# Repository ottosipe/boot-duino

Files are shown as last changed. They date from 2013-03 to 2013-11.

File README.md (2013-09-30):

boot-duino
==========

Arduino-based research project at the University of Michigan. Focusing on an open-source solution to gait and posture analysis.

## Project Status as of Sept. 30, 2013
- Hardware 3.0 is stable
- Software can collect, save, or transmit IMU data.
- Case is designed and being tested.

## Programming

- Program Upload via BT: `make upload`
- Program Upload via AVRisp mkII: `make program`
- Bootloader: `make bootload`
- Fuses: `make fuses`

----

Bluetooth Settings:  
`ST,255` 	- command timer  
`SU,38` 	- baud rate 38400  
`S~,3` 		- Set Modem Profile   

Fuse Info: [Arduino Fuses](http://www.codingwithcody.com/2011/04/arduino-default-fuse-settings/), [Fuse Calculator](http://www.engbedded.com/fusecalc/)

----

Hardware Notes

- Chip Select Pin : D5

----

Install Arduino-Makefile:  

```
sudo perl -MCPAN -e shell
	install YAML
	install Device::SerialPort
```

## Resources and Libraries:
 
- [I2CDev](https://github.com/jrowberg/i2cdevlib)
- [SDFat](http://code.google.com/p/sdfatlib/downloads/list)
- [Arduino-Makefile](https://github.com/mjoldfield/Arduino-Makefile)

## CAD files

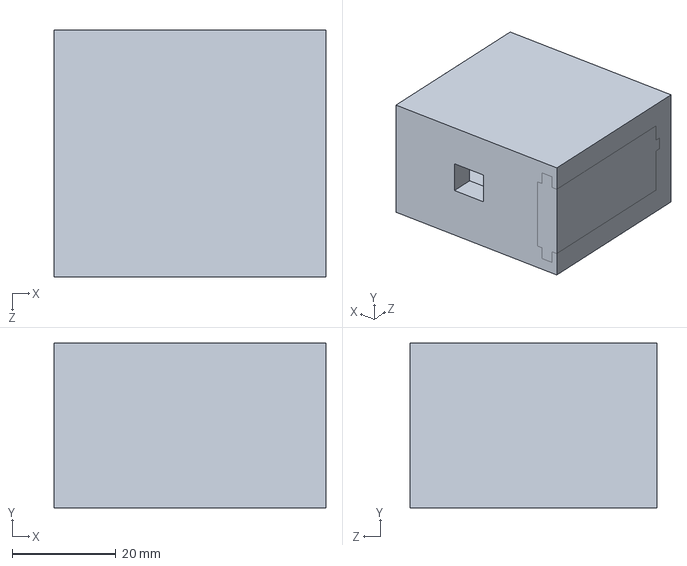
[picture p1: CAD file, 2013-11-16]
Case.SLDPRT
52.4 x 31.8 x 47.6 mm

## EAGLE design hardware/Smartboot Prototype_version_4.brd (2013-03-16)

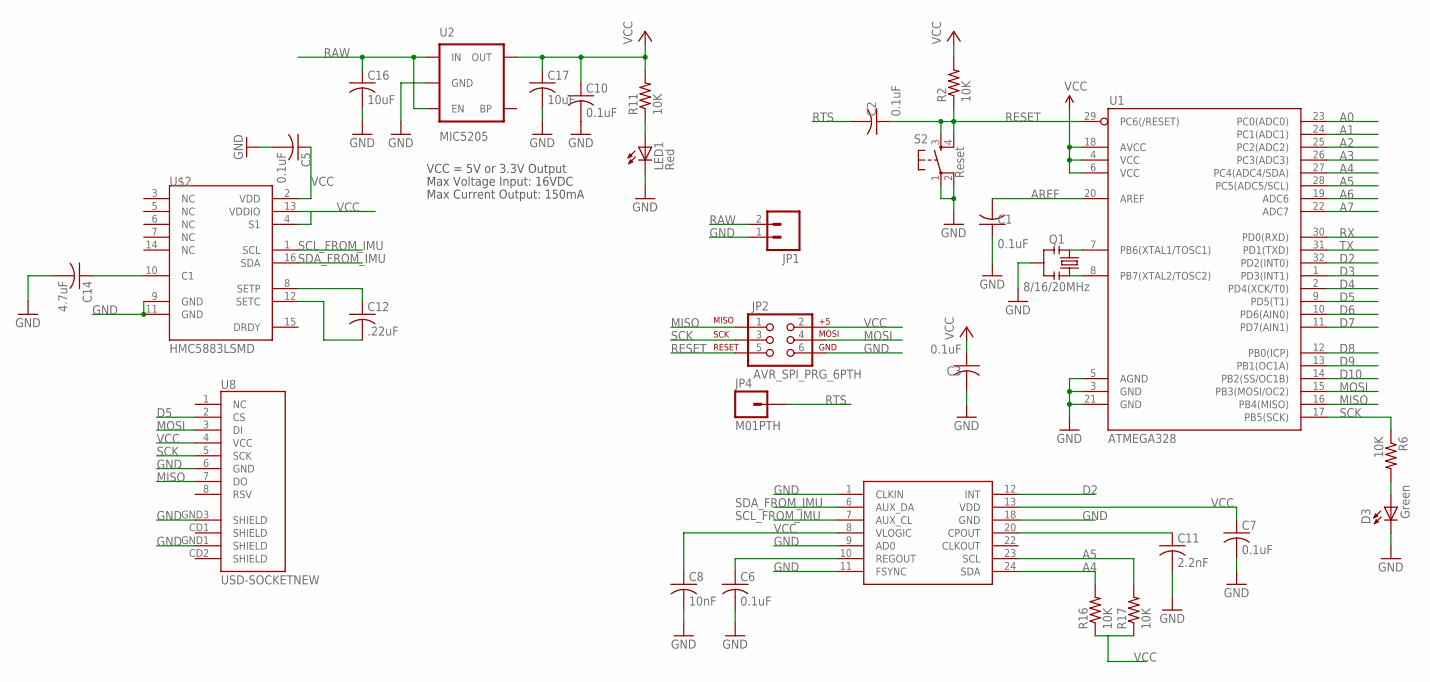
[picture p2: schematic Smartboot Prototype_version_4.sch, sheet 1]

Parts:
C1, C2, C3, C5, C6, C7, C10: 0.1uF; C0603
C8: 10nF; C0603
C11: 2.2nF; C0603
C12: .22uF; C0603
C14: 4.7uF; C0603
C16, C17: 10uF; C0603
D3: Green; LED-0603
JP1: M02-JST-2MM-SMT; JST-2-SMD
JP2: AVR_SPI_PRG_6PTH; 2X3
JP4: M01PTH; 1X01
LED1: Red; LED-0603
Q1: 8/16/20MHz; RESONATOR-SMD
R2, R6, R11, R16, R17: 10K; R0603
S2: Reset; TACTILE_SWITCH_SMD
U1: ATMEGA328; TQFP32-08
U2: MIC5205; SOT23-5
U8: USD-SOCKETNEW; MICRO-SD-SOCKET-PP
U$2: HMC5883LSMD; 16LPCC
U$5: MPU-6050A; QFN-24-NP

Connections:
A0: U1.23 (PC0(ADC0))
A1: U1.24 (PC1(ADC1))
A2: U1.25 (PC2(ADC2))
A3: U1.26 (PC3(ADC3))
A4: R16.2, U1.27 (PC4(ADC4/SDA)), U$5.24 (SDA)
A5: R17.2, U1.28 (PC5(ADC5/SCL)), U$5.23 (SCL)
A6: U1.19 (ADC6)
A7: U1.22 (ADC7)
AREF: C1.2, U1.20 (AREF)
D2: U1.32 (PD2(INT0)), U$5.12 (INT)
D3: U1.1 (PD3(INT1))
D4: U1.2 (PD4(XCK/T0))
D5: U1.9 (PD5(T1)), U8.2 (CS)
D6: U1.10 (PD6(AIN0))
D7: U1.11 (PD7(AIN1))
D8: U1.12 (PB0(ICP))
D9: U1.13 (PB1(OC1A))
D10: U1.14 (PB2(SS/OC1B))
GND: C1.1, C3.2, C5.2, C6.2, C7.2, C8.2, C10.2, C11.2, C14.2, C16.2, C17.2, D3.C, JP1.1 (2), JP2.6, LED1.C, Q1.2, S2.1, S2.2, U1.3 (GND), U1.5 (AGND), U1.21 (GND), U2.2 (GND), U8.6 (GND), U8.GND1 (SHIELD), U8.GND3 (SHIELD), U$2.9 (GND), U$2.11 (GND), U$5.1 (CLKIN), U$5.9 (AD0), U$5.11 (FSYNC), U$5.18 (GND); also elsewhere on the board
MISO: JP2.1, U1.16 (PB4(MISO)), U8.7 (DO)
MOSI: JP2.4, U1.15 (PB3(MOSI/OC2)), U8.3 (DI)
unnamed: Q1.1, U1.8 (PB7(XTAL2/TOSC2))
unnamed: Q1.3, U1.7 (PB6(XTAL1/TOSC1))
unnamed: D3.A, R6.2
unnamed: C12.1, U$2.8 (SETP)
unnamed: C12.2, U$2.12 (SETC)
unnamed: C14.1, U$2.10 (C1)
unnamed: C6.1, U$5.10 (REGOUT)
unnamed: C11.1, U$5.20 (CPOUT)
unnamed: LED1.A, R11.1
RAW: C16.1, JP1.2 (1), U2.1 (IN), U2.3 (EN); also elsewhere on the board
RESET: C2.1, JP2.5, R2.1, S2.3, S2.4, U1.29 (PC6(/RESET))
RTS: C2.2, JP4.1; also elsewhere on the board
RX: U1.30 (PD0(RXD)); also elsewhere on the board
SCK: JP2.3, R6.1, U1.17 (PB5(SCK)), U8.5 (SCK)
SCL_FROM_IMU: U$2.1 (SCL), U$5.7 (AUX_CL)
SDA_FROM_IMU: U$2.16 (SDA), U$5.6 (AUX_DA)
TX: U1.31 (PD1(TXD)); also elsewhere on the board
VCC: C3.1, C5.1, C7.1, C8.1, C10.1, C17.1, JP2.2, R2.2, R11.2, R16.1, R17.1, U1.4 (VCC), U1.6 (VCC), U1.18 (AVCC), U2.5 (OUT), U8.4 (VCC), U$2.2 (VDD), U$2.4 (S1), U$2.13 (VDDIO), U$5.8 (VLOGIC), U$5.13 (VDD); also elsewhere on the board

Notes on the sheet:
Max Voltage Input: 16VDC
Max Current Output: 150mA
VCC = 5V or 3.3V Output

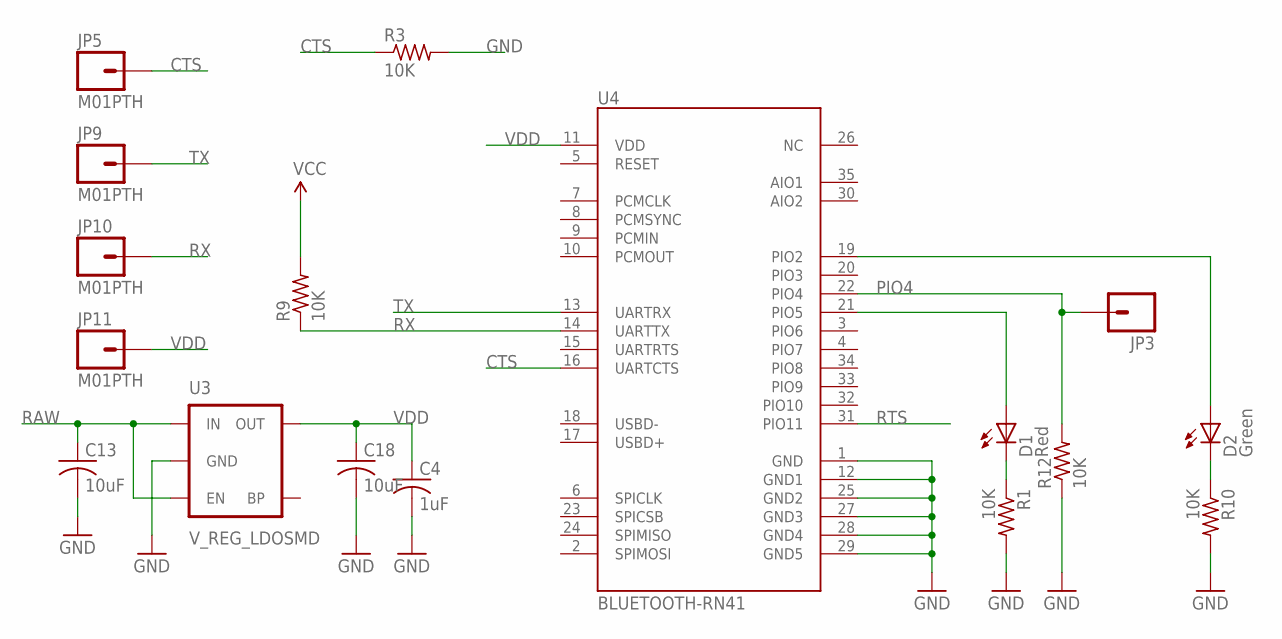
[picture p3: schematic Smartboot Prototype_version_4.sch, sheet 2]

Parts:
C4: 1uF; C0603
C13, C18: 10uF; C0603
D1: Red; LED-0603
D2: Green; LED-0603
JP3: M01SMDNS; 1X01NS
JP5, JP9, JP10, JP11: M01PTH; 1X01
R1, R3, R9, R10, R12: 10K; R0603
U3: V_REG_LDOSMD; SOT23-5
U4: BLUETOOTH-RN41; RN41

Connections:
CTS: JP5.1, R3.1, U4.16 (UARTCTS)
D1: D1.C, R1.1
D11: D2.C, R10.1
GND: C4.2, C13.2, C18.2, R1.2, R3.2, R10.2, R12.1, U3.2 (GND), U4.1 (GND), U4.12 (GND1), U4.25 (GND2), U4.27 (GND3), U4.28 (GND4), U4.29 (GND5); also elsewhere on the board
unnamed: D1.A, U4.21 (PIO5)
unnamed: D2.A, U4.19 (PIO2)
PIO4: JP3.1, R12.2, U4.22 (PIO4)
RAW: C13.1, U3.1 (IN), U3.3 (EN); also elsewhere on the board
RTS: U4.31 (PIO11); also elsewhere on the board
RX: JP10.1, R9.1, U4.14 (UARTTX); also elsewhere on the board
TX: JP9.1, U4.13 (UARTRX); also elsewhere on the board
VCC: R9.2; also elsewhere on the board
VDD: C4.1, C18.1, JP11.1, U3.5 (OUT), U4.11 (VDD)

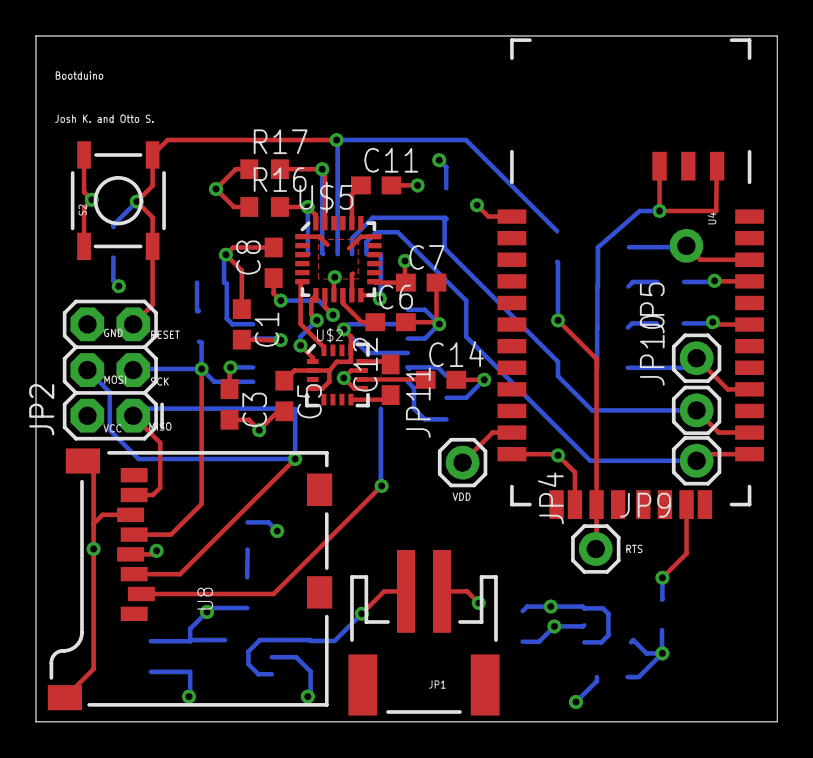
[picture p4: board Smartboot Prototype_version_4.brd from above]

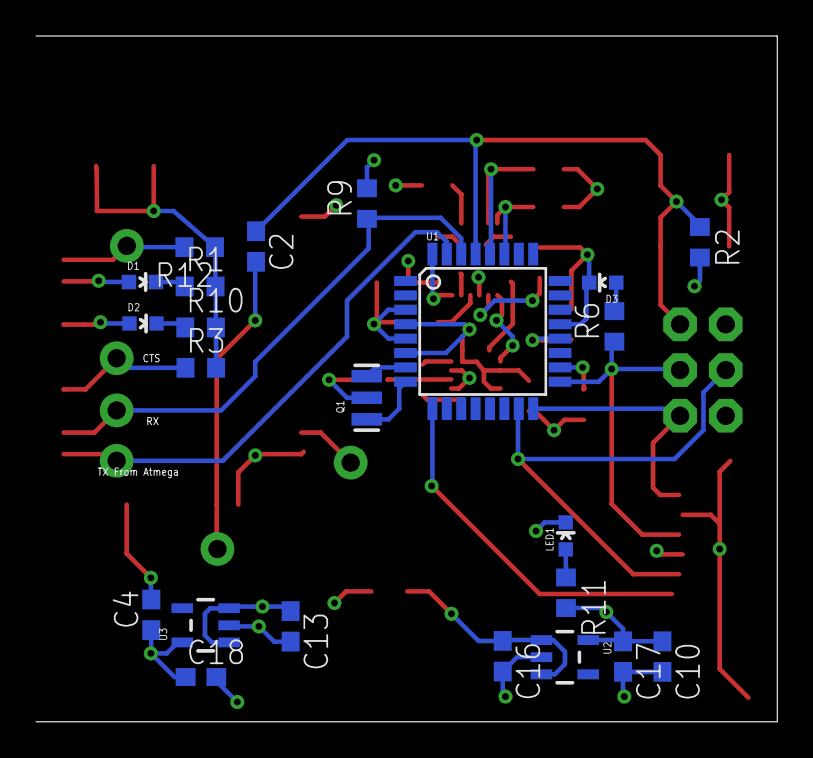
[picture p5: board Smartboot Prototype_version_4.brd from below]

Board: 4 copper layers, 41.2 x 38.1 mm, 47 parts (23 on the bottom side), 33 nets.

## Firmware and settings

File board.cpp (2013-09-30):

#include "board.h"

ArduinoOutStream cout(Serial);

const int chipSelect = 5;
#define LED_PIN 13

#define SD_WRITE

volatile bool mpuInterrupt = false;     
// indicates whether MPU interrupt pin has gone high
void dmpDataReady() {
    mpuInterrupt = true;
}

Board::Board(MPU6050 *imu_in) : imu(imu_in) {  


    pinMode(chipSelect, OUTPUT);
	//scales from datasheet don't change
	scaleAccl = 417.53; //4096 / 9.81 - already shifted for m/s^2 units
	scaleGyro = 32.8; // degrees per second

	dmpReady = false;
	blinkState = false;

	isFirst = true;
};

void Board::start_imu() {
	//init and wake up the board, this should not have to change, only one way to do it!
	imu->initialize();
	int devStatus = imu->dmpInitialize();

	if (devStatus == 0) {
        imu->setDMPEnabled(true);

        attachInterrupt(0, dmpDataReady, RISING);
        mpuIntStatus = imu->getIntStatus();

        dmpReady = true;
        packetSize = imu->dmpGetFIFOPacketSize();
    } else {
        // ERROR!
        // 1 = initial memory load failed
        // 2 = DMP configuration updates failed
        // (if it's going to break, usually the code will be 1)
        Serial.print(F("DMP Initialization failed (code "));
        Serial.print(devStatus);
        Serial.println(F(")"));
    }

	//set ranges
	imu->setFullScaleAccelRange(2); // corresponds to the scaleAccl value
	imu->setFullScaleGyroRange(2); // corresponds to the scaleGyro value

	imu->setRate(4); // 1khz / (1 + 4) = 200 Hz

	#ifdef SD_WRITE
	setup_card();
    file.println("--------------------------");
	#endif
};

Board::~Board() {
	#ifdef SD_WRITE
	close_card();
	#endif
}

void Board::loop() {

	if (!dmpReady) {
		Serial.println("Error, DMP not ready.");
		return;
	}

	// reset interrupt flag and get INT_STATUS byte
    mpuInterrupt = false;
    mpuIntStatus = imu->getIntStatus();

    // get current FIFO count
    fifoCount = imu->getFIFOCount();

	if ((mpuIntStatus & 0x10) || fifoCount == 1024) {
        // reset so we can continue cleanly
        imu->resetFIFO();
        Serial.println(F("FIFO overflow!"));

    // otherwise, check for DMP data ready interrupt (this should happen frequently)
    } else if (mpuIntStatus & 0x02) {
        // wait for correct available data length, should be a VERY short wait
        while (fifoCount < packetSize) fifoCount = imu->getFIFOCount();

        // read a packet from FIFO
        imu->getFIFOBytes(fifoBuffer, packetSize);
        
        // track FIFO count here in case there is > 1 packet available
        // (this lets us immediately read more without waiting for an interrupt)
        fifoCount -= packetSize;

        /*if(isFirst) {
			imu->dmpGetQuaternion(&q, fifoBuffer);
        	imu->dmpGetGravity(&gravity, &q);
        	isFirst = false;
        }*/

        // display initial world-frame acceleration, adjusted to remove gravity
        // and rotated based on known orientation from quaternion
        imu->dmpGetQuaternion(&q, fifoBuffer);
        imu->dmpGetAccel(&aa, fifoBuffer);
        imu->dmpGetGravity(&gravity, &q);
        imu->dmpGetLinearAccel(&aaReal, &aa, &gravity);
        imu->dmpGetLinearAccelInWorld(&aaWorld, &aaReal, &q);
        cout << aa.x / scaleAccl << "," 
        	<< aa.y / scaleAccl << "," 
        	<< aa.z / scaleAccl << ",";

        cout << aaWorld.x / scaleAccl << "," 
            << aaWorld.y / scaleAccl << "," 
            << aaWorld.z / scaleAccl << ";" << endl;
    
        #ifdef SD_WRITE
        file.print(aa.x / scaleAccl);
        file.print(",");
        file.print(aa.y / scaleAccl);
        file.print(",");
        file.print(aa.z / scaleAccl);
        file.print(",");

        file.print(aaWorld.x / scaleAccl);
        file.print(",");
        file.print(aaWorld.y / scaleAccl);
        file.print(",");
        file.print(aaWorld.z / scaleAccl);
        file.println(";");
        #endif

        blinkState = !blinkState;
        digitalWrite(LED_PIN, blinkState);
    }

   	if (Serial.available() && 'x' == Serial.read()) {
		// go to "sleep"
		wait_for_key();	
	}

}

void Board::wait_for_key() {

	Serial.println("Waiting for key ... ");
	while (Serial.available() && Serial.read()); // empty buffer
	while (!Serial.available());                 // wait for data
	while (Serial.available() && Serial.read()); // empty buffer again

}

void Board::setup_card() {

	if (!sd.begin(chipSelect, SPI_HALF_SPEED)) sd.initErrorHalt();
	if (!file.open("data.txt", O_RDWR | O_CREAT | O_AT_END)) {
		sd.errorHalt("Opening data.txt failed!");
	}

}

void Board::close_card() {
	file.close();
}

void Board::read_card() {

	Serial.println("data.txt:");
	// read from the file until there's nothing else in it:
	int data;
	while ((data = file.read()) > 0) Serial.write(data);

}

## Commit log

2013-02-11 initial commit with blink, wireless programming, avr-gcc, and makefile
2013-03-13 working w/ new fuses
2013-03-16 working SD card, added hardware, added libs to makefiles
    [Smartboot Prototype_version_4.brd, Smartboot Prototype_version_4.sch]
2013-03-18 fixed includes, working SD and IMU demo
2013-04-03 fixed header file issues. start of new structure.
    [board.cpp]
2013-11-16 added case design
    [Case.SLDPRT]

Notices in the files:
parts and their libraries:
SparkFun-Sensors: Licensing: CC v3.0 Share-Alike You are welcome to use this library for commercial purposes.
